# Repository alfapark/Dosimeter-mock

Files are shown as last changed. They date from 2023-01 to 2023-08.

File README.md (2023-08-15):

# Dosimeter mock

A game device for outside game. Explore your surroundings, find goals, hide from radiation with a dosimeter device.
The device gathers Wi-fi signals from the surrounding to approximate distance from the objective and radiation strength. 

## Documentation

Documentation is provided in `documents/main.tex`, compile it with your LaTeX compiler.

## Components
- RaspberryPi 4 B
- 4 Digit Display V1.2 (HW-069) 
- RFID-RC522
- Powerbank

## Pins
- 4 Digit Display V1.2 (HW-069)
  - CLK - GPIO 3 (5)
  - DIO - GPIO 2 (3)
  - VCC - 3.3V (1)
  - GND - GND(6)
- RFID-RC522
  - SDA - GPIO 8 (24)
  - SCK - GPIO 11 (23)
  - MOSI - GPIO 10 (19)
  - MISO - GPIO 9 (21)
  - IRQ - Not used
  - GND - GND (20)
  - RST - GPIO 25 (22)
  - 3.3V - 3.3V (17)
- Button
 - Power - 5V (4)
 - Detect - GPIO 4 (7)
- LEDS
  - L1 - GPIO 5 (29)
  - L2 - GPIO 6 (31)
  - L3 - GPIO 13 (33)
  - L4 - GPIO 19 (35)
  - L5 - GPIO 26 (37)
  - L6 - GPIO 20 (38)
  - Status - GPIO 21 (40)
  - Radiation - GPIO 16 (36)
  - GND - GND (39)

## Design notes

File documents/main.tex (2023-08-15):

\documentclass{article}
\usepackage[utf8]{inputenc}
\usepackage{fullpage}
\usepackage{graphicx}
\usepackage{hyperref}
\usepackage{wrapfig}
\usepackage{fancyhdr}
\usepackage[ 
left=2.5cm,
right=2.5cm, 
top=3cm, 
bottom=3cm,
headheight = 3.5\baselineskip,
headsep = 5mm,
a4paper
]{geometry}

\setlength{\headheight}{16pt}
\pagestyle{fancy}
\renewcommand{\headrulewidth}{0.2pt} % no line in header area
\fancyhead{}
\pagestyle{fancy}
\fancyhf{}
\lhead{Computational Aspects of Digital Fabrication}
\rhead{Jan Pokorný}
\rfoot{\thepage}
\title{Dosimeter game}
\begin{document}

{\huge{Dosimeter game: Info sheet}}

\begin{center}
    \centering
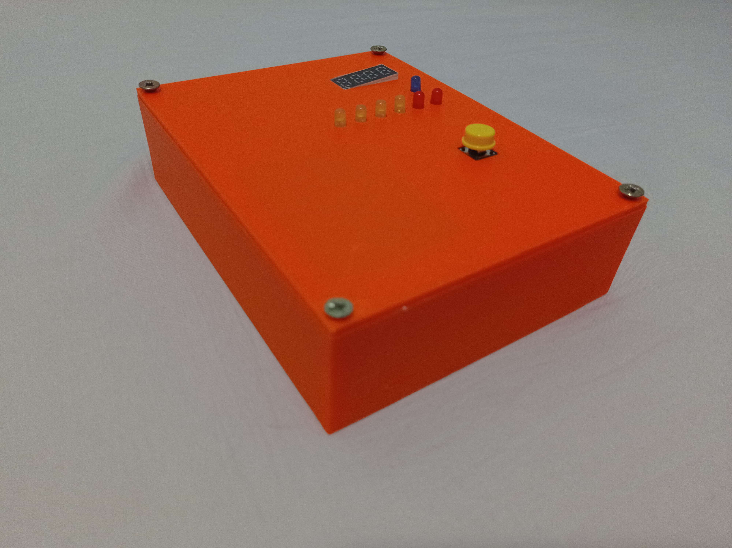
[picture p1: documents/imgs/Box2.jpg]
    
\end{center}

\section{Game}
The goal of the game is to survive and find a NFC tag. 
The player gathers information about its surrounding through a device.
The device gives the player a rough distance from the goal item and a strength of the radiation.
If the player is area with radiation, he loses health points.
If the health points of the player ever reaches a zero, the game is over.

\subsection{Controls}
\begin{enumerate}
\item Use the NFC card to restart the device by putting it next to the NFC reader (slightly darker rectangle, left of the button).
\item Press the button to change the displayed information. The display displays these types of information:
\begin{itemize}
\item Goal(G): The distance (not in meters - signal strength from the ) from the goal.
\item Time: Time since the beginning of the game.
\item Radiation(r): Amount of radiation the player is receiving. The higher the radiation, the faster loses the player health points. 
\item Health(H): Number of health points remaining, if this counter reaches zero, the game ends.
\item Shield(S): Shield time remaining.
\item Wait(W): How much waiting is done in percent.
\item Objective(O): Number of the current objective.
The letter in parentheses is displayed as the first character on the display.
\end{itemize}
\item Monitor the health bar, the fewer LEDs are lit up, the lower the amount of health points the player has.
\item Find the NFC tag and put it next to the NFC reader. The display now shows how fast you were.
\end{enumerate}

\emph{Be carefully with the device, too quick movements with it may damage the components inside.}

\section{How to make}
    The creation process includes 3D modeling and printing of the custom box of the device as well as programming of a microprocessor as the tool of digital fabrication.
    Other employed techniques are soldering and hot gun gluing.

\begin{wrapfigure}{r}{0.5\textwidth}
    \centering
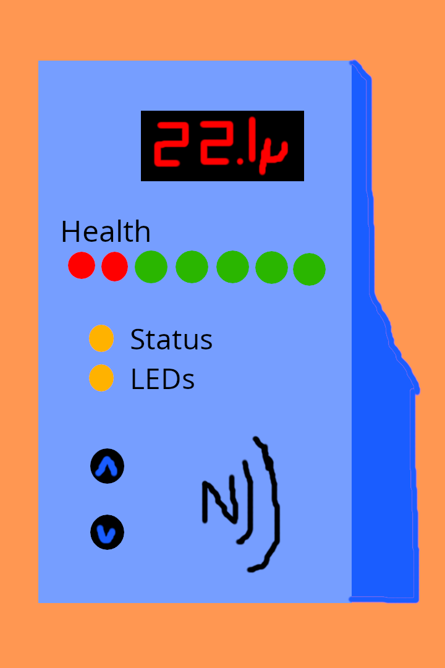
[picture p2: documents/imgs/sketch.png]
    
    \caption{First sketch of the device.}
\end{wrapfigure}

\subsection{Components}
The main components are:
\begin{itemize}
    \item RaspberryPi 4 B
    \item 4 Digit Display V1.2 (HW-069) 
    \item RFID-RC522
    \item Powerbank
\end{itemize}
Furthemore, standard components for RPi as LEDs, button, cables were used.

\subsection{PIN layout} \label{pins}
\begin{itemize}
    \item Digit Display V1.2 (HW-069)
        \begin{itemize}
            \item CLK - GPIO 3 (5)
            \item DIO - GPIO 2 (3)
            \item VCC - 3.3V (1)
            \item GND - GND(6)
        \end{itemize}
    \item RFID-RC522
        \begin{itemize}
            \item SDA - GPIO 8 (24)
            \item SCK - GPIO 11 (23)
            \item MOSI - GPIO 10 (19)
            \item MISO - GPIO 9 (21)
            \item IRQ - Not used
            \item GND - GND (20)
            \item RST - GPIO 25 (22)
            \item 3.3V - 3.3V (17)
        \end{itemize}
    \item Button
        \begin{itemize}
            \item Power - 5V (4)
            \item Detect - GPIO 4 (7)
        \end{itemize}
    \item LEDS
        \begin{itemize}
            \item L1 - GPIO 5 (29)
            \item L2 - GPIO 6 (31)
            \item L3 - GPIO 13 (33)
            \item L4 - GPIO 19 (35)
            \item L5 - GPIO 26 (37)
            \item L6 - GPIO 20 (38)
            \item Radiation LED - GPIO 16 (36)
            \item Status - GPIO 21 (40)
            \item GND - GND (39)
        \end{itemize}
\end{itemize}

\subsection{Extra components}
To be able to play the game you additionally need NFC tags and devices capable to emit Wi-fi signal.

The device is able to detect the Wi-fi networks automatically if you name them following this naming scheme.
Networks named \texttt{DM-radiation} will display as radiation and harm the player if he gets too close.
Other network names have pattern \texttt{DM-N-Name}, where \texttt{N} is the number of the objective in which the network plays its role and \texttt{Name} further specifies the objective.
The name \texttt{defend} is satisfied when the device is enough time in the proximity of the network. 
Other objectives are either satisfied with the \texttt{NEXT} or \texttt{GOAL} NFC tag.
It is also possible to specify their ESSID in the \texttt{config.json} to use existing networks.
The NFC tags have to be named correctly:
\begin{itemize}
    \item \texttt{GOAL} -- wins the game.
    \item \texttt{HP} -- sets the player health points to 100.
    \item \texttt{NEXT} -- changes the objective to the next objective.
    \item \texttt{RESET} -- restarts the game.
    \item \texttt{SHIELD} --  prevents radiation for 30 seconds.
\end{itemize}
To name the tags, the file \texttt{write.json} may be used.

\subsection{Tutorial}
    Depending on the exact components used, the device may differ.
    The provided STL \texttt{models/box.stl} expects standard Arduino/RaspberryPi LEDs nad button and 43x91 mm powerbank.
    To adjust the 3D model, change parameters in \texttt{models/box.scad} using \emph{OpenSCAD}.
    Both models are contained in a single file to be able to see how components line up.
    For printing the model has to be split up into two pieces and rotated correspondingly. 

\begin{figure}[ht]
    \centering
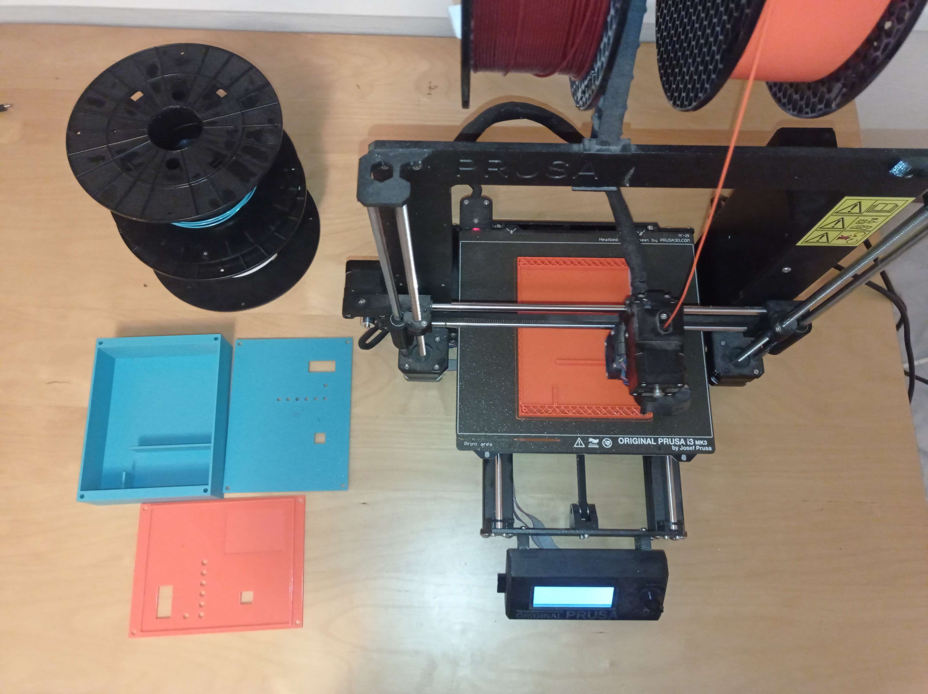
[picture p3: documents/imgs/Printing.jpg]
    
    \caption{3D printing of provided models.}
\end{figure}

    The component \emph{RFID-RC522} has to be soldered. 
\begin{figure}[ht]
    \centering
    \begin{tabular}{cc}
        \label{soldering}
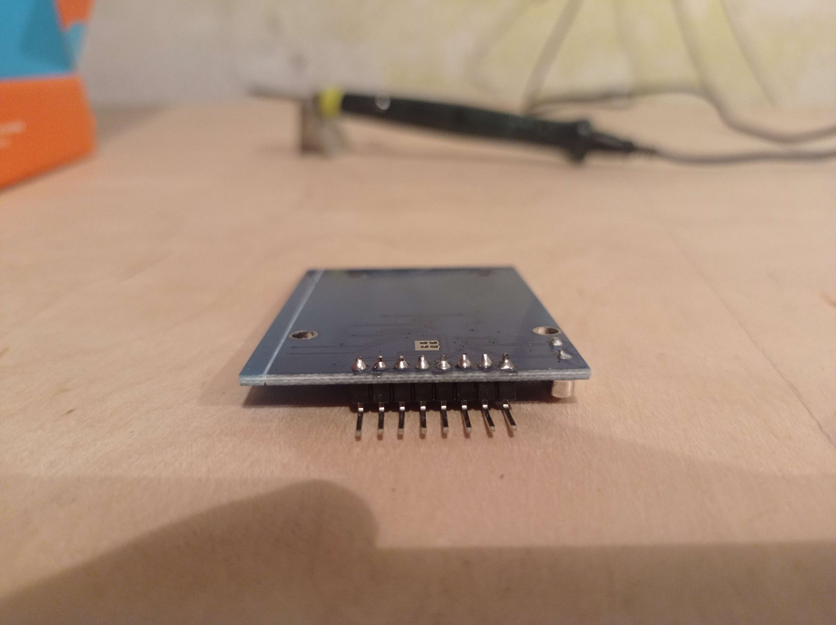
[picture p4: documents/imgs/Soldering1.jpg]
        
        &
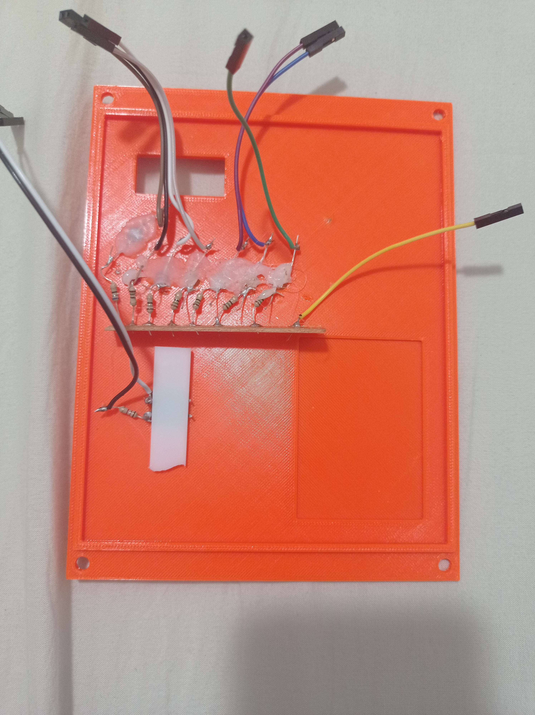
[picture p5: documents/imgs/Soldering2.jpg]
        
    \end{tabular}
    \caption{Soldering of the component \emph{RFID-RC522}on the left and soldering of the LEDs and the button on the right.}
\end{figure}

    Every LED is connected with a resistor to adjust the amount of current it goes through. 
    All LEDs are connected to a shared ground (yellow) and each of them has its own controlling pin.
    They are connected to the upper box part by a glue gun.
    The button is permanently attached with by a glue gun as well.
    The exact wiring is shown in figure \ref{soldering} and then in figure \ref{wiring}.

    Every component is connected to the Raspberry Pi as described in section \ref{pins}. 
    The display is attached to the upper part of the box with tight fit.
    The NFC reader is attached by a clear sticky tape.

\begin{figure}[ht]
    \label{wiring}
    \centering
    \begin{tabular}{cc}
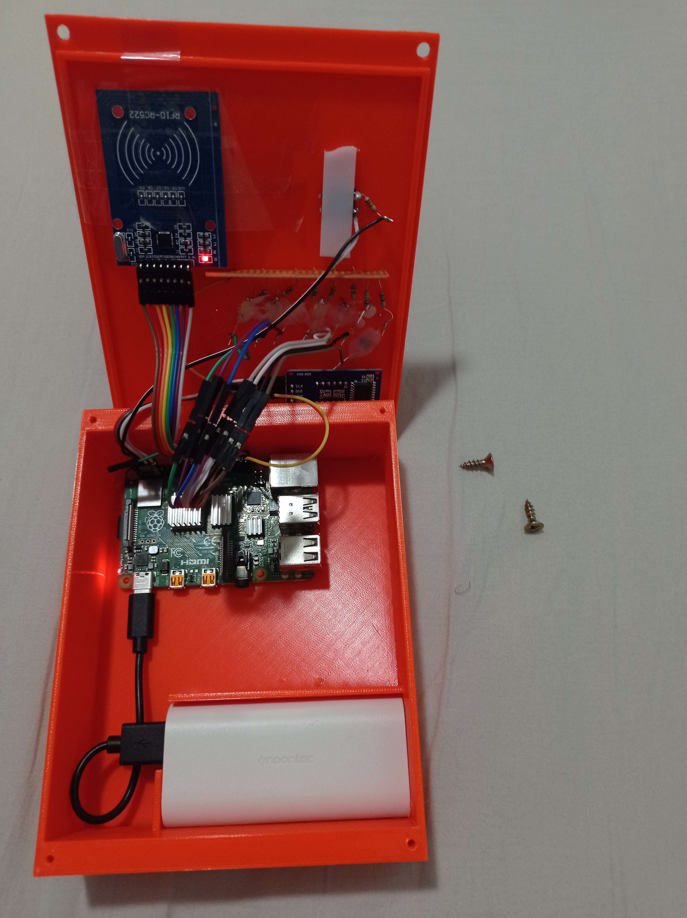
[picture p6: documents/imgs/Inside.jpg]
        
        &
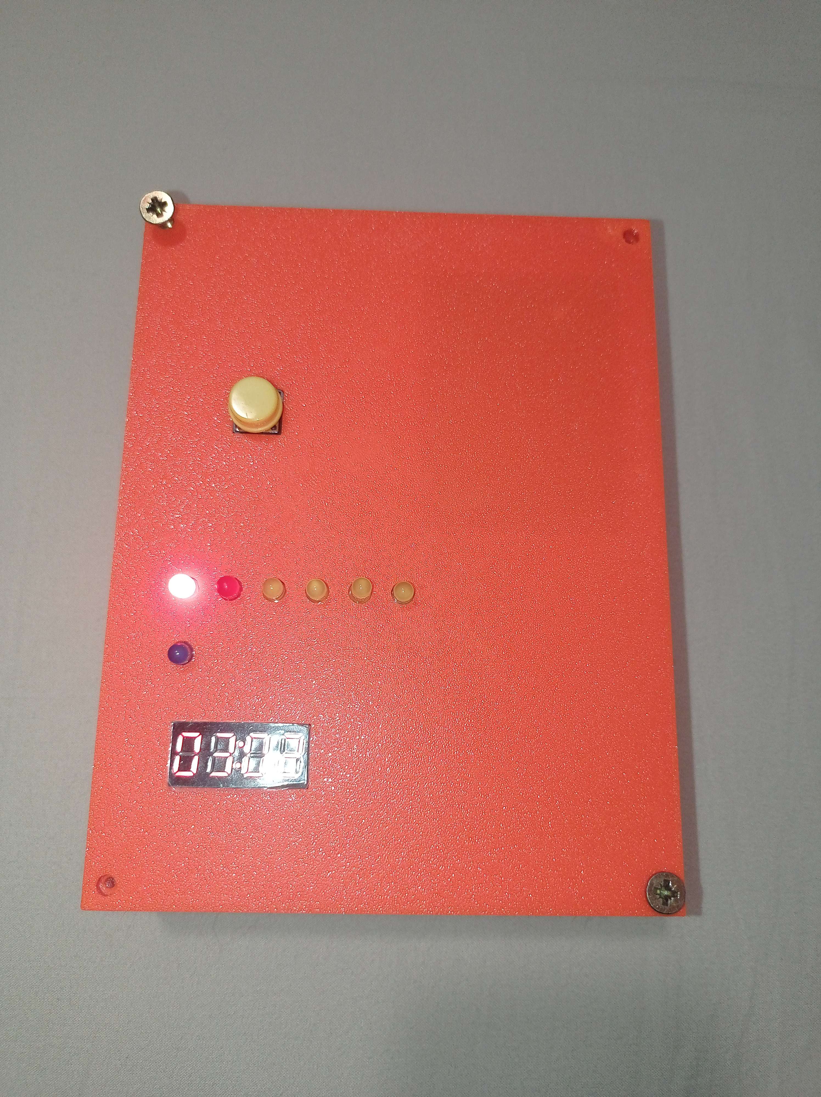
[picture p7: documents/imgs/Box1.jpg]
        
    \end{tabular}
    \caption{The device from the inside on the left and completed running device on the right.}
\end{figure}

    To turn the device on run \texttt{main.py}.
    Required packages are listed in \texttt{requirements.txt}

    The code, models and other assets are on GitHub: \url{https://github.com/alfapark/Dosimeter-mock}.

\subsection{Known issues}
\begin{itemize}
    \item The device may overheat. Raspberry Pi generates a lot of heat and the provided box has no air ventilation.
    \item Config addresses are not handled properly at the moment.
    \item The RFID reader works only with new empty RFID chips, writing to them with any other app different from the provided python script \texttt{write.py} might render them unreadable by the device.
    \item The display is rotated by 180 degrees due to the wiring. 
    \item Refresh rate of the networks is too slow.
\end{itemize}

\subsection{Declaration}
    The project was done entirely by its single author Jan Pokorny as a project for subject Computational Aspects of Digital Fabrication at TU Wien. 
    The involvement of other people was only through discussion of technical details and borrowing of their equipment which I am thankful for.
\end{document}

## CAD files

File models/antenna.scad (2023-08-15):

module antenna(big_radius, small_radius, mounting_height, cone_height, upper_height){
    cylinder(r=big_radius, h=mounting_height);
    translate([0,0,mounting_height])
        cylinder(r1=big_radius, r2=small_radius, h=cone_height);
    translate([0,0,mounting_height+cone_height])
        cylinder(r=small_radius, h=upper_height);
    translate([0,0,mounting_height+cone_height+upper_height])
        sphere(r=small_radius);
}

antenna(9.9, 5, 10, 80, 20);

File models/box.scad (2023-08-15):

use <radiation.scad>
use <signal.scad>

// shear such that point will translate by [p.x,p.y] as z-axis is traversed by p.z units
// https://gist.github.com/thehans/c30c259e83da4e89ccbd975a511dab68
module shearAlongZ(p) {
  multmatrix([
    [1,0,p.x/p.z,0],
    [0,1,p.y/p.z,0],
    [0,0,1,0]
  ]) children();
}

module box_upper(
size_x, // x size of the lid
size_y, // y size of the lid
thickness, // thickness of the lid
screw_offset, // both x and y offset for screw hole from the corner to the center of the hole
screw_hole_size,
rectangle_holes, // array of [x,y, size_x, size_y] - x,y is the ofset to the left upper corner
circle_holes, // array of [x,y, diameter] - x,y is the offset from center
pegs, // array of [x,y, size_x, size_y, size_z, shear_x, shear_y]
bridges, // array of [x,y,size_x,size_y,size_z]
){
    offset_x = thickness;
    offset_y = 2*screw_offset;
    new_x=size_x+2*offset_x;
    new_y=size_y+2*offset_y;
    difference(){
        union(){
            cube([size_x+2*thickness, size_y+4*screw_offset, thickness]);
            //brim
            translate([thickness,2*screw_offset,-thickness])
            difference(){
                    cube([size_x, size_y, thickness]);
                    translate([thickness, thickness,0])
                    cube([size_x-2*thickness, size_y-2*thickness, thickness]);
            }
        }
        // screw holes
        for(screw_x = [screw_offset, new_x-screw_offset]){
            for(screw_y = [screw_offset, new_y - screw_offset]){
                translate([screw_x, screw_y, 0])
                    cylinder(h = thickness, d = screw_hole_size);
            }
        }
        // other holes
        for(object = rectangle_holes){
            translate([object[0]+offset_x, object[1]+offset_y,-object[4]])
                cube([object[2], object[3], thickness]);
        }
        for(object = circle_holes){
            translate([object[0]+offset_x, object[1]+offset_y,0])
                cylinder(h=thickness, d=object[2]);
        }
        
        /* Not printable for now */
        translate([offset_x, offset_y, thickness])
            mirror([0,0,1])
                children();
    }
    for(peg = pegs){
        translate([peg[0]+offset_x-peg[5], peg[1]+offset_y-peg[6], -peg[4]])
        shearAlongZ([peg[5],peg[6],peg[4]])
            cube([peg[2], peg[3], peg[4]]);
    }
    for(bridge = bridges){
        translate([bridge[0]+offset_x, bridge[1]+offset_y-thickness, -bridge[4]]){
                cube([bridge[2], thickness, bridge[4]]);
            translate([0,0,-thickness])
                cube([bridge[2], bridge[3]+2*thickness, thickness]);
            translate([0, bridge[3]+thickness, 0])
                cube([bridge[2], thickness, bridge[4]]);
        }
    }
}

module box_lower(
    size_x, // x size of the box
    size_y, // y size of the box
    size_z, // z size (height) of the box
    thickness, // thickness of the lid
    screw_offset, // both x and y offset for screw hole from the corner to the center of the hole
    screw_hole_size,
    walls, // array of [x,y, size_x, size_y, size_z] - x,y is the offset to the left upper corner,
    columns, // array of [x,y, diameter, height]
    antenna_width,
    antenna_height
){
    offset_x = thickness;
    offset_y = 2*screw_offset;
    offset_z = thickness;
    new_x=size_x+2*offset_x;
    new_y=size_y+2*offset_y;
    new_z=size_z+offset_z;
    difference(){
        cube([new_x, new_y, new_z]);
        translate([thickness, 2*screw_offset, thickness])
            cube([size_x, size_y, size_z]);
        // screw holes
        for(screw_x = [screw_offset, new_x-screw_offset]){
            for(screw_y = [screw_offset, new_y - screw_offset]){
                translate([screw_x, screw_y, 0])
                    cylinder(h = new_z, d = screw_hole_size);
            }
        }
    }
    for(object = walls){
        translate([object[0]+offset_x, object[1]+offset_y, offset_z])
            cube([object[2], object[3], object[4]]);
    }
    
    for(object = columns){
        translate([object[0]+offset_x, object[1]+offset_y, offset_z])
            cylinder(d = object[2], h = object[3]);
    }
    // anntenna
    translate([0, new_y,0]){
        difference(){
            cube([antenna_width+thickness, antenna_width+thickness, antenna_height+thickness]);
            translate([(antenna_width+thickness)/2,(antenna_width+thickness)/2, thickness])
            cylinder(d=antenna_width, h=antenna_height);
        }
    }
}
size_x = 125;
size_y = 150;
translate([0,0, 200])
box_upper(
size_x=size_x,
size_y=size_y,
thickness=2.5,
screw_offset=5,
screw_hole_size=5,
rectangle_holes=[
    [80, 120, 31, 14.5,0], // display
    [90, 40, 12, 12,0], // button 
    [10, 10, 43, 61, 1.5] // NFC 
], 
circle_holes=[
    [60,90,6], // HP
    [70,90,6],
    [80,90,6],
    [90,90,6],
    [100,90,6],
    [110,90,6],
    [110,105,6], // status
    [30, 120,6], // radiation
],
pegs=[
    [7.5,20, 3,3, 5, 5, 0], // NFC
    [53,20, 3,3, 5, -5, 0],
    [7.5,55, 3,3, 5, 5, 0],
    [53,55, 3,3, 5, -5, 0],
    [80, 120-3, 31, 3, 4,0,0], // display support
    [80+31, 120-3, 3, 14+6, 4,0,0], 
    [80, 120+14, 31, 3, 4,0,0], 
],
bridges=[
    [80, 43, 4, 6, 3], // button 
    [108, 43, 4, 6,3], // button 
]
){
    linear_extrude(height=0.5)
        translate([30, 120])
            radiation(25, 5, 3);
    linear_extrude(height=0.5)
        translate([31, 40])
            signal(4, 3);};
// calculating mounting for rpi
rpi_screw1_x = 10;
rpi_screw1_y = 146;
rpi_length = 85;
rpi_width = 56;
rpi_screw_to_side = 4;
rpi_wall_x = rpi_screw1_x-rpi_screw_to_side+rpi_length;
rpi_wall_y = rpi_screw1_y+rpi_screw_to_side-rpi_width;
box_lower(
size_x=size_x,
size_y=size_y,
size_z =40,
thickness=2.5,
screw_offset=5,
screw_hole_size=3,
walls=[
    [size_x-91-2.5, 0, 2.5, 20, 22], // powerbank short
    [size_x-90,44,91,2.5,22], // powerbank long
    [rpi_wall_x, rpi_wall_y, 2.5, 150-(rpi_wall_y), 3], // rpi vertical mini wall
    [0, rpi_wall_y-2.5, rpi_wall_x+2.5, 2.5, 3], // rpi horizontal mini wall
],
columns=[
    [rpi_screw1_x,rpi_screw1_y,2.7,5], // RPI screw columns
    [rpi_screw1_x+58,rpi_screw1_y,2.7,5],
    [rpi_screw1_x,rpi_screw1_y-49,2.7,5],
    [rpi_screw1_x+58,rpi_screw1_y-49,2.7,5]
],
antenna_width=10,
antenna_height=10
);

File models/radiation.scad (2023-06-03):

module radiation(radius,inner_radius,border){
    for(r = [0,120,240]){
        rotate(r)
            difference(){
                intersection(){
                    circle(radius);
                    square(radius);
                    rotate(30)
                        square(radius);
                }
                circle(inner_radius+border);
            }
    }
    circle (inner_radius);
}

radiation(20,3,2);                 

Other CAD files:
models/signal.scad

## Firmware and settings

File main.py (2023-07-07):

import RPi.GPIO as GPIO
import time
import network_scanner
import sys
from threading import Thread
from enum import Enum
import traceback
import json

from healthbar import HealthBar
from read import Reader
from display import Display
from button import Button

# address = sys.argv[1]

def load_json_file(file_location):
    data = dict()
    try:
        with open(file_location) as json_file:
            data = json.load(json_file)
    except FileNotFoundError:
        pass
    return data

class State(Enum):
    RADIATION = 1
    TIME = 2
    HEALTH = 3
    GOAL_DISTANCE = 4
    SHIELD = 5
    WAIT = 6
    OBJECTIVE = 9
    FINISHED = 10
    DEAD = 11

next_state = {
    State.FINISHED: State.FINISHED,
    State.DEAD: State.DEAD,
    State.RADIATION : State.TIME,
    State.TIME : State.HEALTH,
    State.HEALTH : State.GOAL_DISTANCE,
    State.GOAL_DISTANCE : State.SHIELD,
    State.SHIELD : State.WAIT,
    State.WAIT : State.OBJECTIVE,
    State.OBJECTIVE : State.RADIATION,
}

class DosimeterMock:
    def __init__(self):
        self.set_initial_state()
        #GPIO Basic initialization
        GPIO.setmode(GPIO.BCM)
        GPIO.setwarnings(True)

        self.status_led_pin = 21
        GPIO.setup(self.status_led_pin,GPIO.OUT)
        self.radiation_led_pin = 16
        GPIO.setup(self.radiation_led_pin,GPIO.OUT)

        leds = [20,26,19,13,6,5]
        self.HPBar = HealthBar(leds, maxval=self.HP)

        self.display = Display(clk_pin=3, dio_pin=2)

        self.button = Button(4)
        self.button_hold_last_time = False

        self.parse_config()

        self.NFC_MSG = None        
        self.NFC_ID = None        
        self.WIFI_signals = dict()

    def parse_config(self):
        try:
            config_dict = load_json_file("config.json")
            self.goal_address = config_dict["goal_adr"]
            self.radiation_addresses = config_dict["radiation_adrs"]
        except:
            self.goal_address = "invalid"
            self.radiation_addresses = []

    def set_initial_state(self):
        self.state = State.GOAL_DISTANCE
        self.radiation_strength = 0
        self.goal_distance = 100
        self.HP = 100
        self.start = time.time()
        self.status_time = time.time()
        self.shield_time = time.time()
        self.last_radiation_up = time.time()
        self.wait_time = None
        self.to_do_state = 1
        self.seen_NFC = set()


    def status_led_up(self):
        GPIO.output(self.status_led_pin, True)
        self.status_time = time.time() + 0.2

    def update_status_led(self):
        if self.status_time < time.time():
            GPIO.output(self.status_led_pin, False)

    def update_radiation_led(self):
        if self.last_radiation_up > time.time() + 0.2:
            GPIO.output(self.radiation_led_pin, False)
        diff = (time.time() - self.last_radiation_up)
        if self.radiation_strength > 0 and diff/self.radiation_strength < 0.05:
            GPIO.output(self.radiation_led_pin, True)
            self.last_radiation_up = time.time()

    def get_elapsed_seconds(self):
        elapsed = time.time() - self.start
        return int(elapsed)

    def check_NFC(self):
        msg = self.NFC_MSG
        id = self.NFC_ID
        self.NFC_MSG = None
        self.NFC_ID = None
        if msg is None:
            return
        msg = msg.strip()
        print(msg)
        if msg[0].isnumeric():
            level = int(msg)
            if self.to_do_state == level:
                self.to_do_state +=1
        if id in self.seen_NFC:
            return
        if msg == "HP" :
            self.HP = 100
            self.seen_NFC.add(id)
        if msg == "NEXT":
            self.to_do_state += 1
        elif msg[4] == "GOAL" and int(msg[5:]) == self.to_do_state:
            self.state = State.FINISHED
        elif msg == "RESET":
            self.set_initial_state()
        elif msg == "SHIELD":
            self.shield_time = time.time() + 30
            self.seen_NFC.add(id)

    def handle_state(self):
        button_hold = self.button.is_hold()
        if button_hold and not self.button_hold_last_time:
            self.state = next_state[self.state]
        self.button_hold_last_time = button_hold

        if self.state == State.TIME:
            self.display.display_time(self.get_elapsed_seconds())
        elif self.state == State.HEALTH:
            self.display.display_number('H', self.HP)
        elif self.state == State.RADIATION:
            self.display.display_number('R', self.radiation_strength)
        elif self.state == State.GOAL_DISTANCE:
            self.display.display_number('G', self.goal_distance)
        elif self.state == State.SHIELD:
            self.display.display_number('S', max(self.shield_time-time.time(), 0))
        elif self.state == State.WAIT:
            self.display.display_number('W', self.wait_time)
        elif self.state == State.OBJECTIVE:
            self.display.display_number('O', self.to_do_state)
        elif self.state not in [State.FINISHED, State.DEAD]:
            raise Exception("Wrong state: " + str(self.state))

    def check_game(self):
        if self.HP <= 0:
            self.state = State.DEAD
            self.display.display_text("dead")
        if self.state == State.FINISHED:
            self.display.display_time(self.get_elapsed_seconds())

    def game_ended(self):
        return self.state in [State.DEAD, State.FINISHED]

    def handle_network(self):
        signals = self.WIFI_signals
        self.goal_distance = 999
        self.radiation_strength = 0
        for address in signals:
            essid = signals[address]['ESSID'] 
            essid = essid[1:-1]
            if address in self.radiation_addresses or essid == 'DM-radiation':
                self.radiation_strength += network_scanner.parse_signal_strength(signals[address]) + 100
                continue
            if essid[0:3] != 'DM-':
                # TODO addresses from config
                continue 
            order = essid[3:]
            if '-' in order:
                dash_index = order.index('-')
                quest = order[dash_index+1:]
                order = order[0:dash_index]
            order = int(order)
            print(order, quest)

            if order == self.to_do_state:
                self.goal_distance = -network_scanner.parse_signal_strength(signals[address])
                if quest == "defend":
                    if self.wait_time is None:
                        self.wait_time = 100
                    self.wait_time -= max(100 - self.goal_distance, 0)/200
                    if self.wait_time <= 0:
                        self.wait_time = None
                        self.to_do_state += 1
                        self.status_led_up()

    def update_HP(self):
        if self.shield_time < time.time():
            self.HP -= self.radiation_strength/1000

    def loop(self):
        NFC_thread = Thread(target=self.NFC_reading, args=[])
        NFC_thread.start()
        WIFI_thread = Thread(target=self.WIFI_reading, args=[])
        WIFI_thread.start()
        while True:
            while not self.game_ended():
                try:
                    print("cycle")
                    self.update_status_led()
                    self.update_radiation_led()
                    self.handle_network()
                    self.HPBar.display(self.HP)
                    self.check_NFC()
                    self.handle_state()
                    self.check_game()
                    self.update_HP()
                except Exception as e:
                    traceback.print_exc()
                    print('Exception', str(e))
                time.sleep(0.1)
            self.status_led_up()
            self.check_NFC()
            time.sleep(0.1)


    def NFC_reading(self):
        reader = Reader()
        while True:
            id,text = reader.read()
            self.status_led_up()
            print(id, text)
            self.NFC_MSG = text
            self.NFC_ID = id
            time.sleep(1)

    def WIFI_reading(self):
        while True:
            WIFI_signals = network_scanner.parse_interface()
            self.WIFI_signals = WIFI_signals
            time.sleep(1)


if __name__ == "__main__":
    dm = DosimeterMock()
    dm.loop()

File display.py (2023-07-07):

import tm1637
import time

class Display:
    def __init__(self, clk_pin, dio_pin):
        self.tm = tm1637.TM1637(clk=clk_pin, dio=dio_pin)

    def display_time(self, elapsed):
        minutes, seconds = int(elapsed//60), int(elapsed) % 60 
        self.tm.numbers(minutes, seconds)

    def display_number(self, letter, number):
        if number is None:
            self.tm.show(letter + "---")
            return
        number = int(number)
        chars = letter + str(number).zfill(3)
        self.tm.show(chars)

    def display_text(self, text):
        self.tm.show(text)


if __name__ == "__main__":
    # all LEDS on "88:88"
    tm.write([127, 255, 127, 127])
    time.sleep(1)
    # all LEDS off
    tm.write([0, 0, 0, 0])
    time.sleep(1)
    # show "0123"
    tm.write([63, 6, 91, 79])
    time.sleep(1)
    # show "COOL"
    tm.write([0b00111001, 0b00111111, 0b00111111, 0b00111000])
    time.sleep(1)
    # show "HELP"
    tm.show('help')
    time.sleep(1)
    # display "dEAd", "bEEF"
    tm.hex(0xdead)
    tm.hex(0xbeef)
    time.sleep(1)
    # show "-123"
    tm.number(-123)
    time.sleep(1)
    # show temperature '24*C'
    tm.temperature(24)

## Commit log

2023-01-06 box bottom
    [box.scad]
2023-01-06 box tweaking first version
    [box.scad]
2023-01-08 box tweaking parameters
    [box.scad]
2023-01-25 box stl + basic code
    [box.stl]
2023-01-25 button and refactor
2023-01-26 timer reset
2023-01-26 handle wifi signals - thread
2023-01-26 thread target is method
2023-01-26 status led
2023-01-26 status led fix
2023-01-26 status led fix2
2023-01-26 status led not wifi
2023-06-03 upper part pegs
    [box.scad]
2023-06-03 upper part display support
    [box.scad]
2023-06-03 radiation+signal incorporated
    [box.scad]
2023-06-03 bridges for button
    [box.scad]
2023-06-04 rpi mounting, removed symbols
    [box.scad]
2023-07-07 radiation led
2023-08-15 update documentation
    [antenna.scad, box.scad, box.stl]
